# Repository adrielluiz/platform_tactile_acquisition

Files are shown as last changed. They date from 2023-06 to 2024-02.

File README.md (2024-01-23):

# Dynamic Tactile Data Acquisition Platform

### Overview

This repository hosts a Dynamic Tactile Data Acquisition Platform,  designed to facilitate tactile experiments across two axes (X and Z). It is a versatile tool aimed at researchers and engineers involved in tactile data collection and analysis.

### Features

- **Two-Axis Movement**: Precision-engineered to operate along both X and Z axes, ensuring comprehensive coverage for tactile experiments.
- **Dual Stepper Motors**: Employs two robust stepper motors, delivering smooth and accurate motion control.
- **Microcontroller**: Utilizes an STM32F401 MCU.
- **Integrated System Components**:
  - **Firmware**: C/C++ firmware for platform control.
  - **Software Interface**: A user-friendly Python-based software interface for movement planning and execution.
  - **Serial Communication**: Seamless serial communication protocol linking the software and firmware components.

### Repository Contents

- **Mechanical Structure 3D Files**: Detailed 3D models of the platform's mechanical structure for easy replication or modification.
- **Firmware Variants**: Two distinct firmware versions tailored to different stepper motor drivers.
- **Control Software**: Intuitive software designed for seamless interaction with the microcontroller unit.
- **PCB Design and Layout Files**: Comprehensive files for the printed circuit board (PCB) design.

### Getting Started

Please refer to the individual folders.

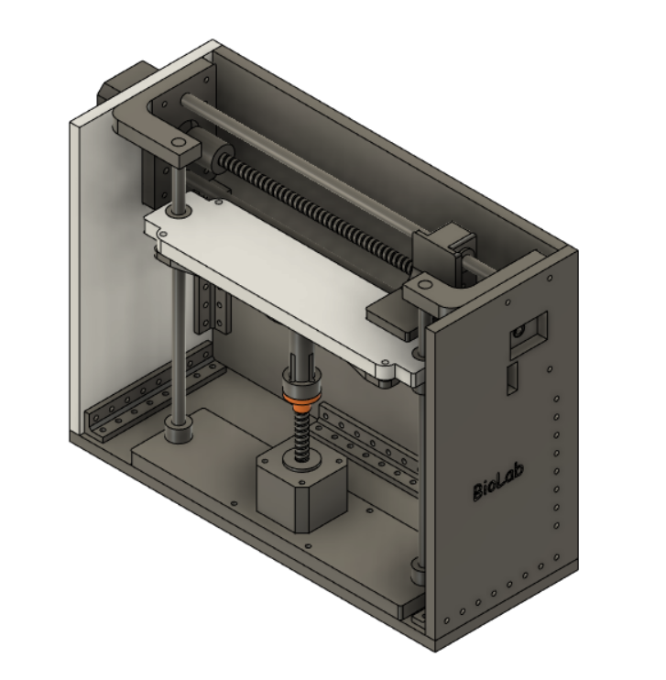
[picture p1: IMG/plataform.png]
plot


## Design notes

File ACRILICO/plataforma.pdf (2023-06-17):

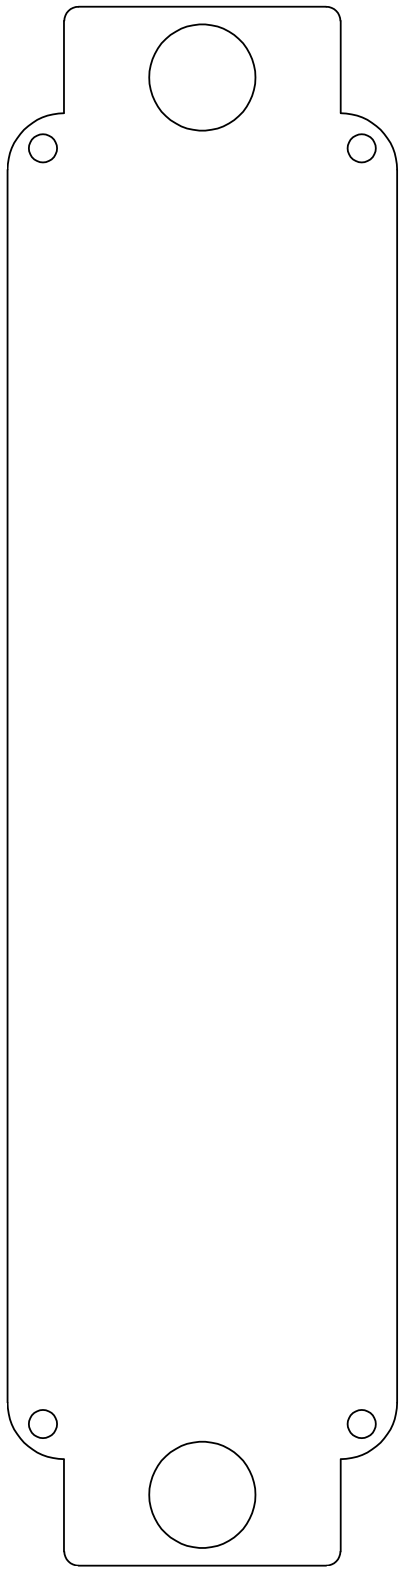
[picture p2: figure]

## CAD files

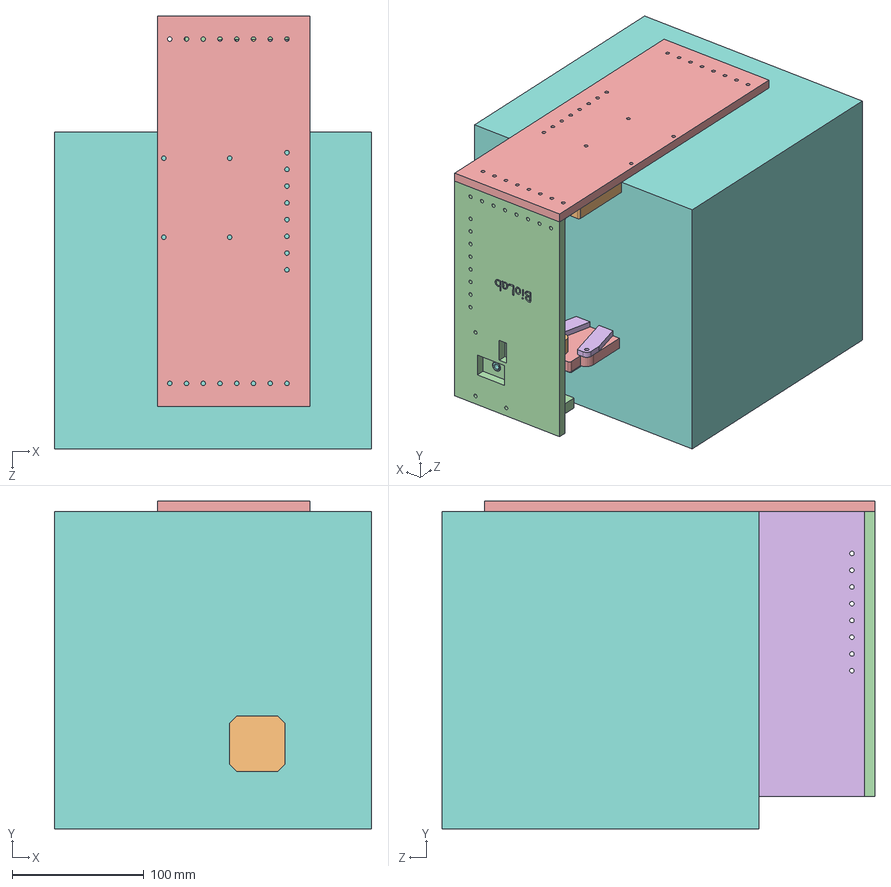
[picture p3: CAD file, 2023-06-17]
3D_files/MontagemPlataforma2.SLDASM
240.8 x 248.8 x 328.8 mm
SuporteMotor
motorPasso
acoplador
ContraApoioMotor
plataforma
suportePlataforma
guia200_5mm x 2
fusoTrapazoidal172_5mm
Rolamento
RolamentoLinear x 4
corredor
SensorFimdeCurso
motorPasso para fuso
fusoTrapazoidal100_8mm
Castanha x 2
guia175.43_8mm x 2
suporteFusoGuiaMotor
acrilico1
acrilico2
acrilico3
acrilico4
cantoneira x 5

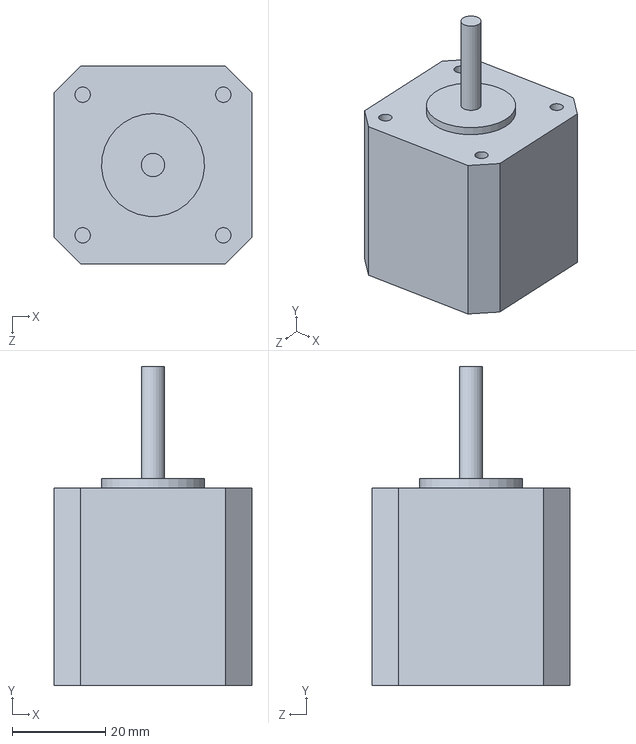
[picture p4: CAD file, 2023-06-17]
3D_files/motorPasso.SLDPRT
42.3 x 68.3 x 42.3 mm

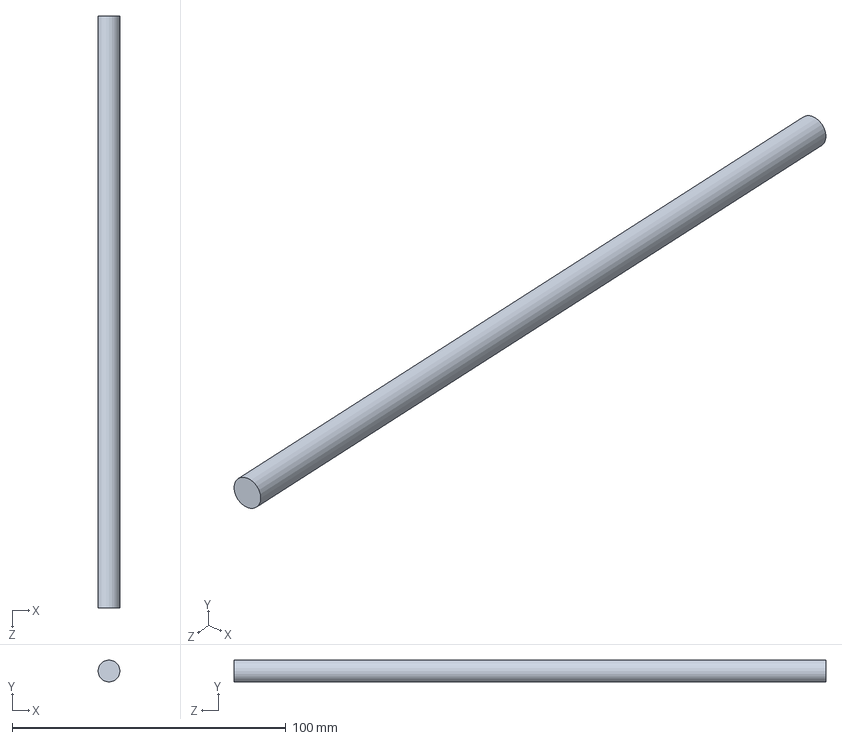
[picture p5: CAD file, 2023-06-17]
3D_files/guia175.43_8mm.SLDPRT
8.00 x 8.00 x 216.2 mm

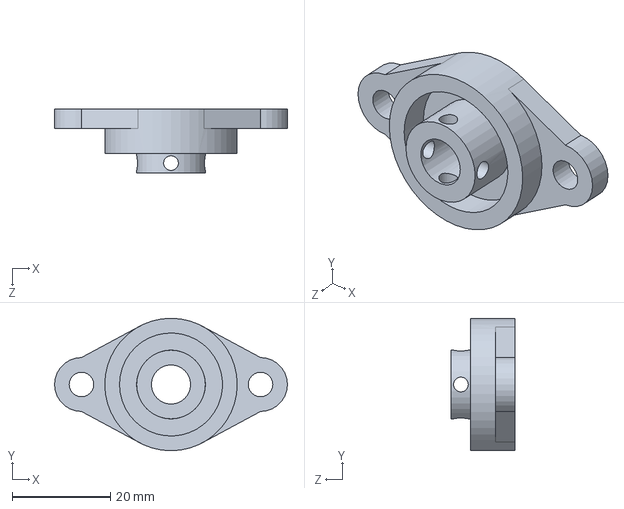
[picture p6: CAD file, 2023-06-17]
3D_files/Rolamento.SLDPRT
47.5 x 27.0 x 13.0 mm

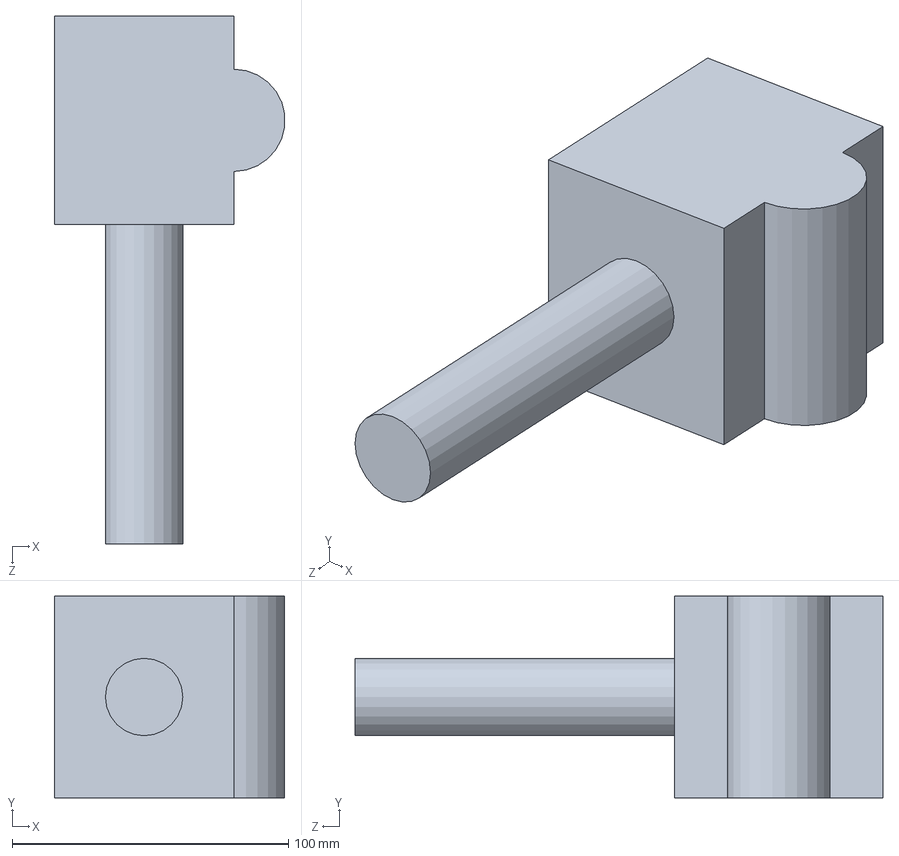
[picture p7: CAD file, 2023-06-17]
3D_files/macaco.SLDPRT
83.4 x 73.0 x 191.0 mm

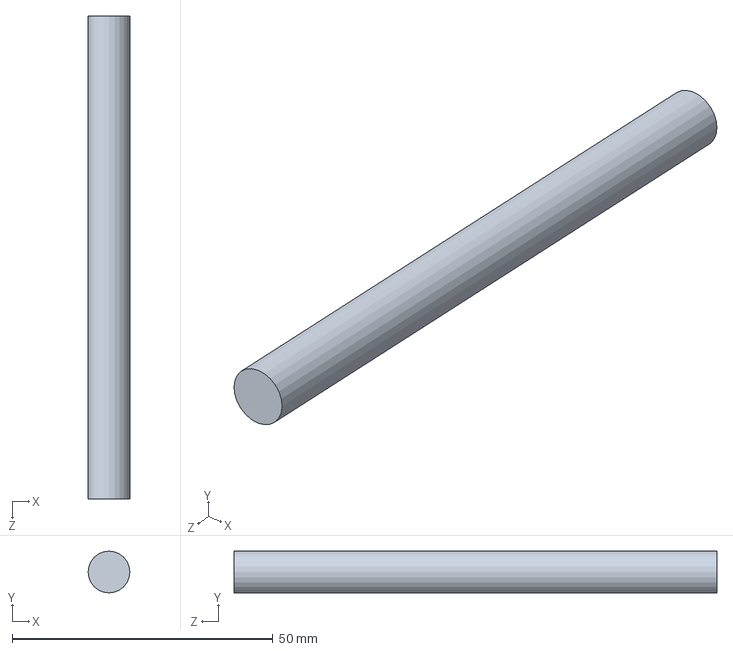
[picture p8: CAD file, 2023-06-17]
3D_files/guia146_8.SLDPRT
8.00 x 8.00 x 92.6 mm

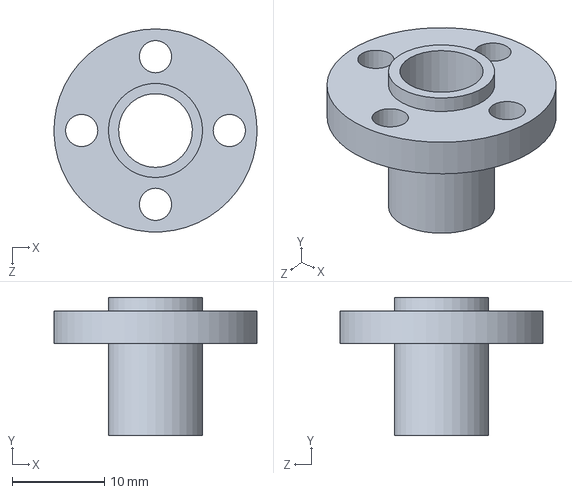
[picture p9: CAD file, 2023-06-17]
3D_files/Castanha.SLDPRT
22.0 x 15.0 x 22.0 mm

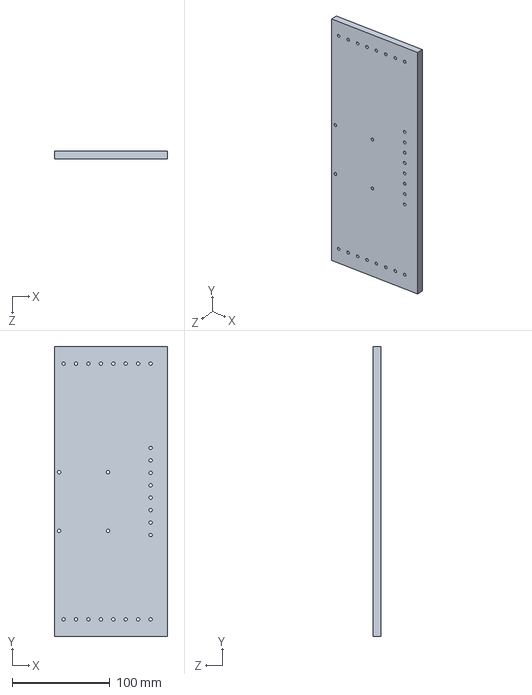
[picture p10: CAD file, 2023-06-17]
3D_files/acrilico3.SLDPRT
116.0 x 296.5 x 8.00 mm

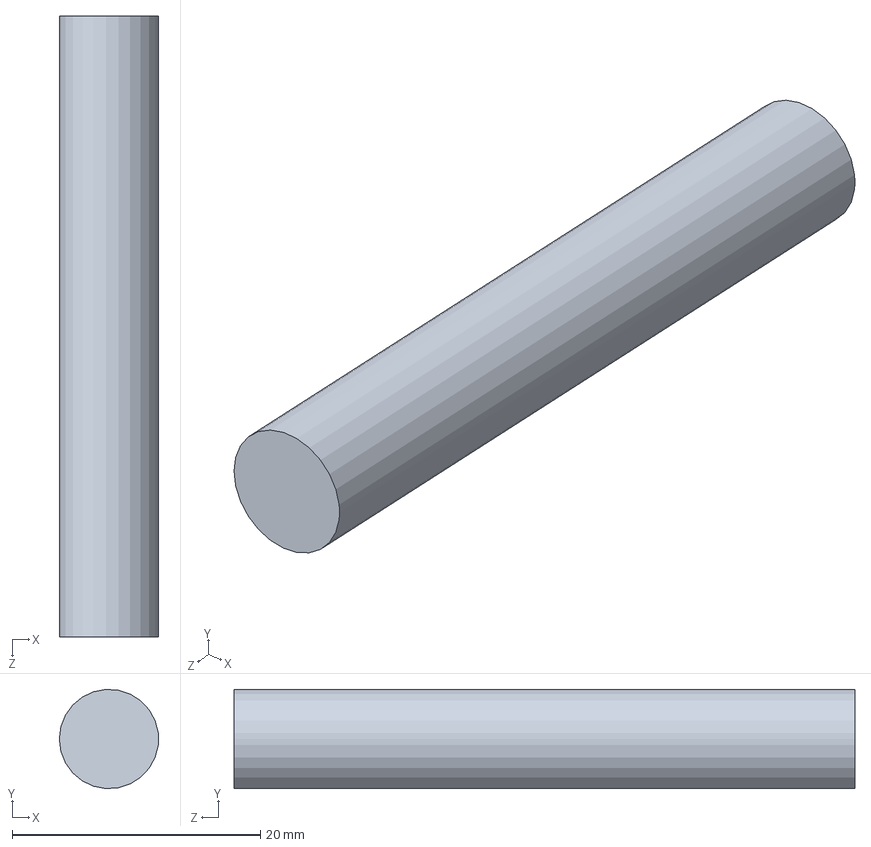
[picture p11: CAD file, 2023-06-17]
3D_files/guia100_8.SLDPRT
8.00 x 7.98 x 50.0 mm

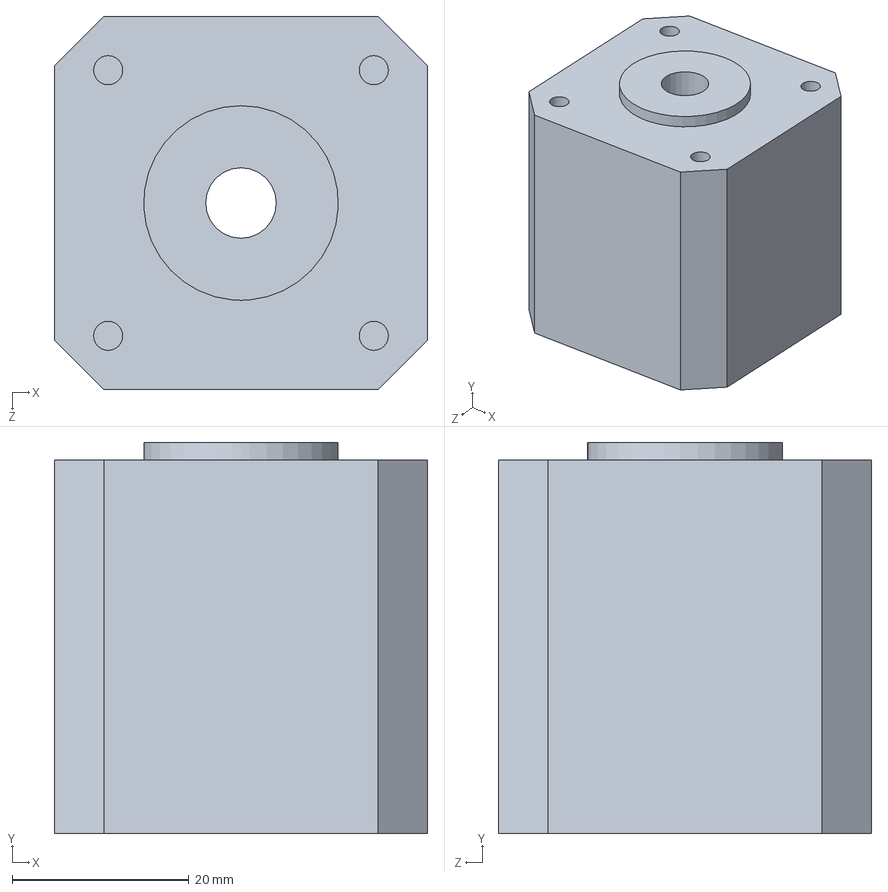
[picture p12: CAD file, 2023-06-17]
3D_files/motorPasso para fuso.SLDPRT
42.3 x 44.3 x 42.3 mm

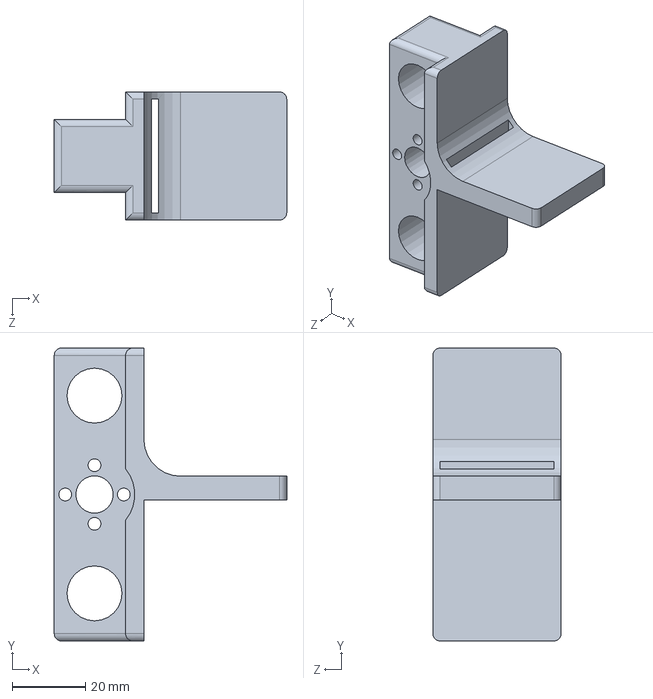
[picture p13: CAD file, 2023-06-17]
3D_files/corredor.SLDPRT
63.5 x 80.0 x 35.0 mm

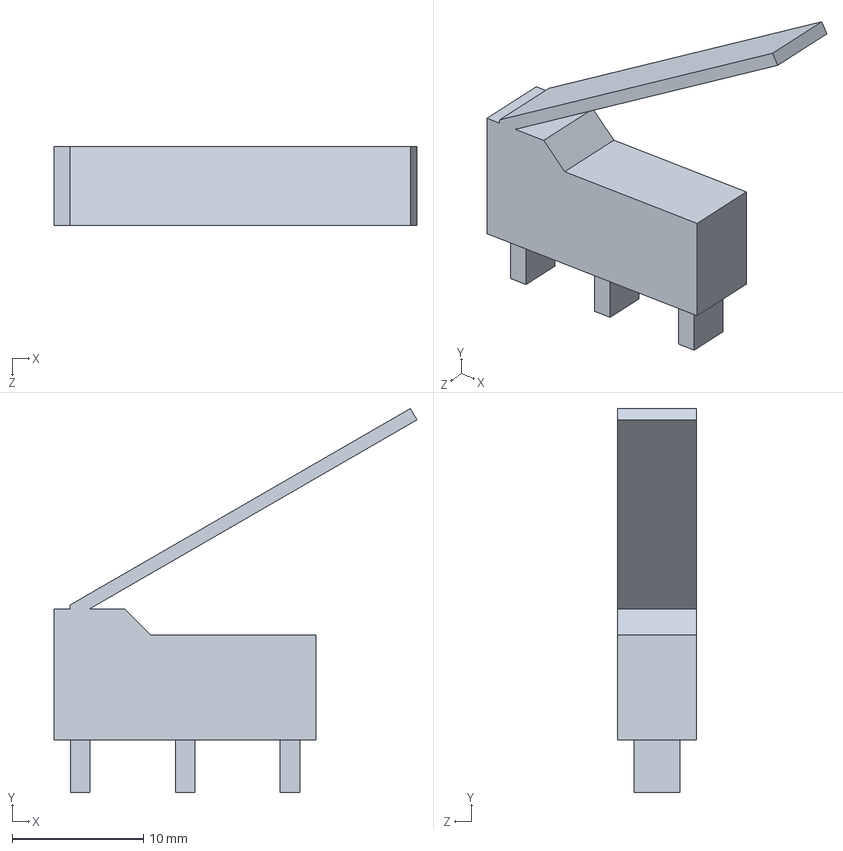
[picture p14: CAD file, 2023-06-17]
3D_files/SensorFimdeCurso.SLDPRT
27.7 x 29.3 x 6.00 mm

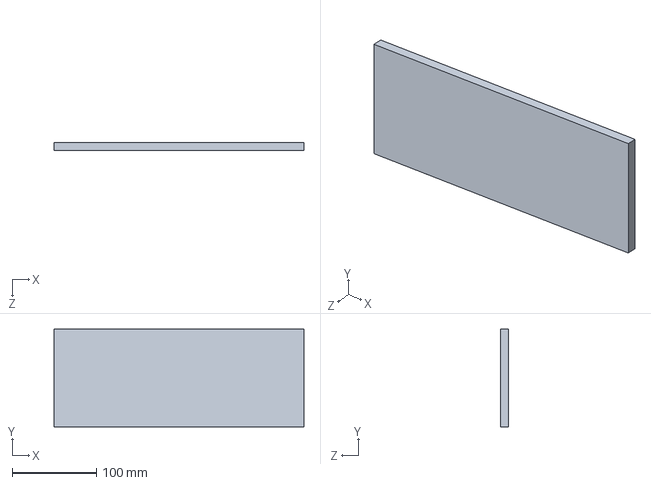
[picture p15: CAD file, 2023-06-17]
3D_files/acrilico5.SLDPRT
296.5 x 116.0 x 10.0 mm

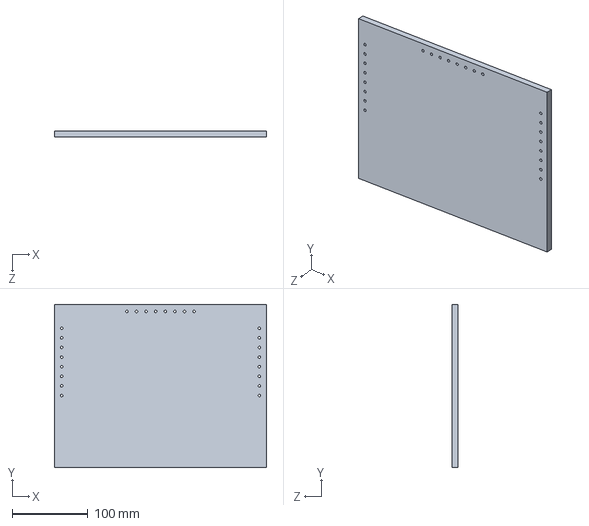
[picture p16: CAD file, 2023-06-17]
3D_files/acrilico4.SLDPRT
280.5 x 216.2 x 8.00 mm

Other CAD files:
3D_files/guia200_5mm.SLDPRT
3D_files/fusoTrapazoidal172_5mm.SLDPRT
3D_files/cantoneira.SLDPRT
3D_files/SuporteMotor.SLDPRT
3D_files/ContraApoioMotor.SLDPRT
3D_files/RolamentoLinear.SLDPRT
3D_files/acoplador.SLDPRT
3D_files/acoplador_guiamotor.SLDPRT
3D_files/acrilico1.SLDPRT
3D_files/acrilico2.SLDPRT
3D_files/box.SLDPRT
3D_files/fuso240mm.SLDPRT
3D_files/fusoTrapazoidal100_8mm.SLDPRT
3D_files/fusoTrapazoidal105_5mm.SLDPRT
3D_files/fusoTrapazoidal240mm - Copia.SLDPRT
3D_files/fusoTrapazoidal240mm.SLDPRT
3D_files/guia240mm.SLDPRT
3D_files/plataforma.SLDPRT
3D_files/suporteFusoGuiaMotor.SLDPRT
3D_files/suportePlataforma.SLDPRT

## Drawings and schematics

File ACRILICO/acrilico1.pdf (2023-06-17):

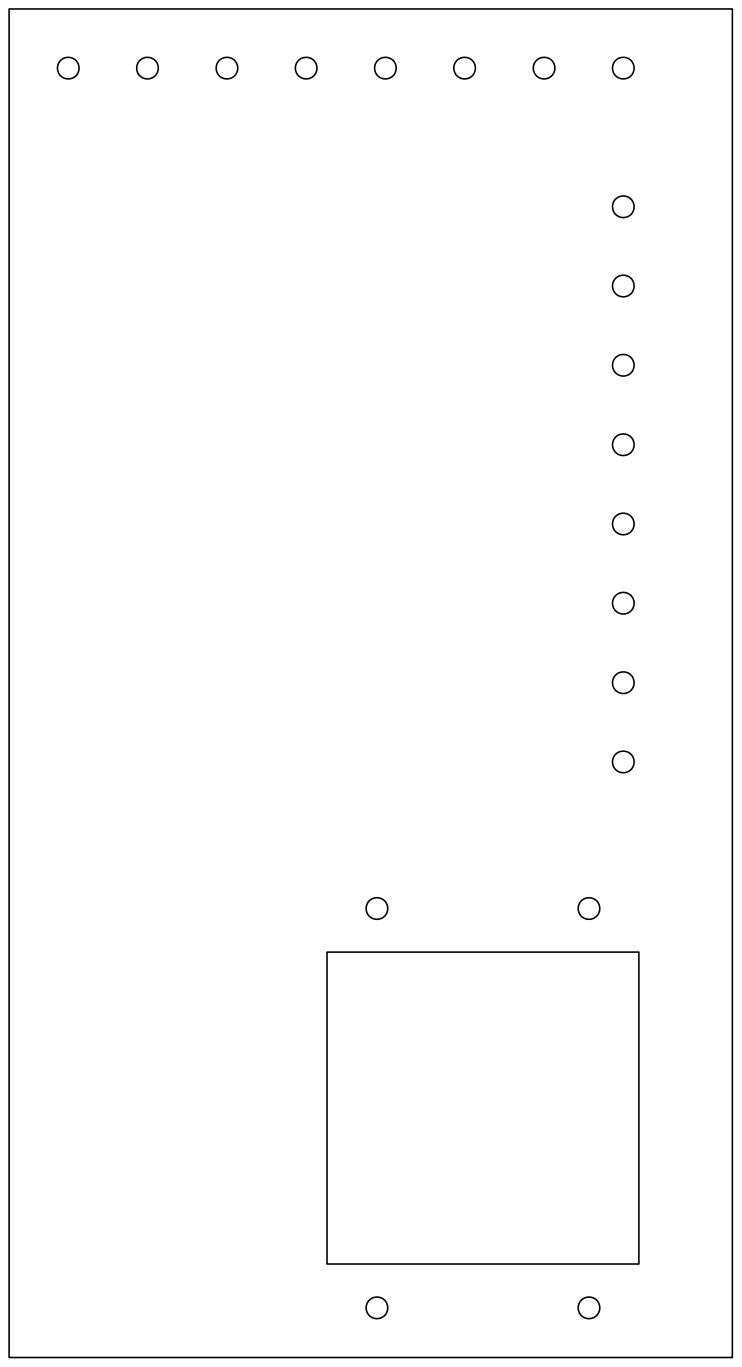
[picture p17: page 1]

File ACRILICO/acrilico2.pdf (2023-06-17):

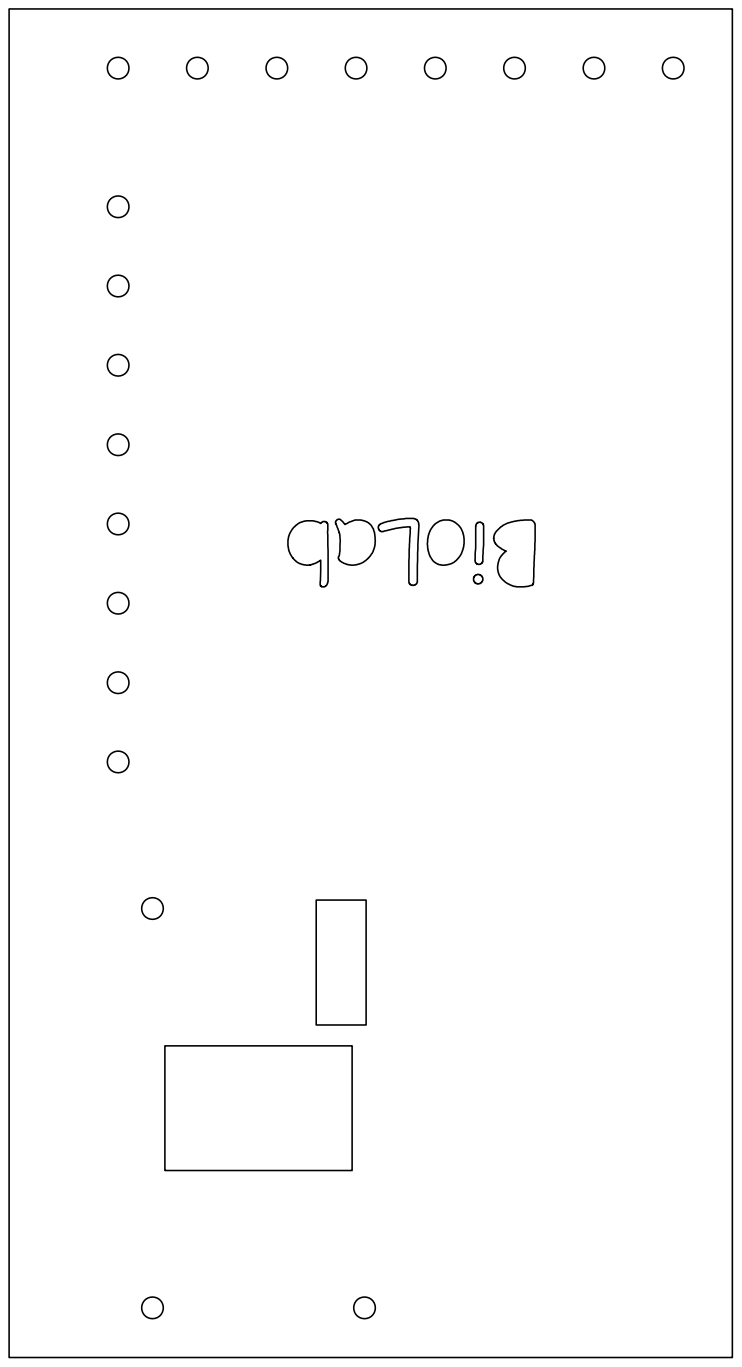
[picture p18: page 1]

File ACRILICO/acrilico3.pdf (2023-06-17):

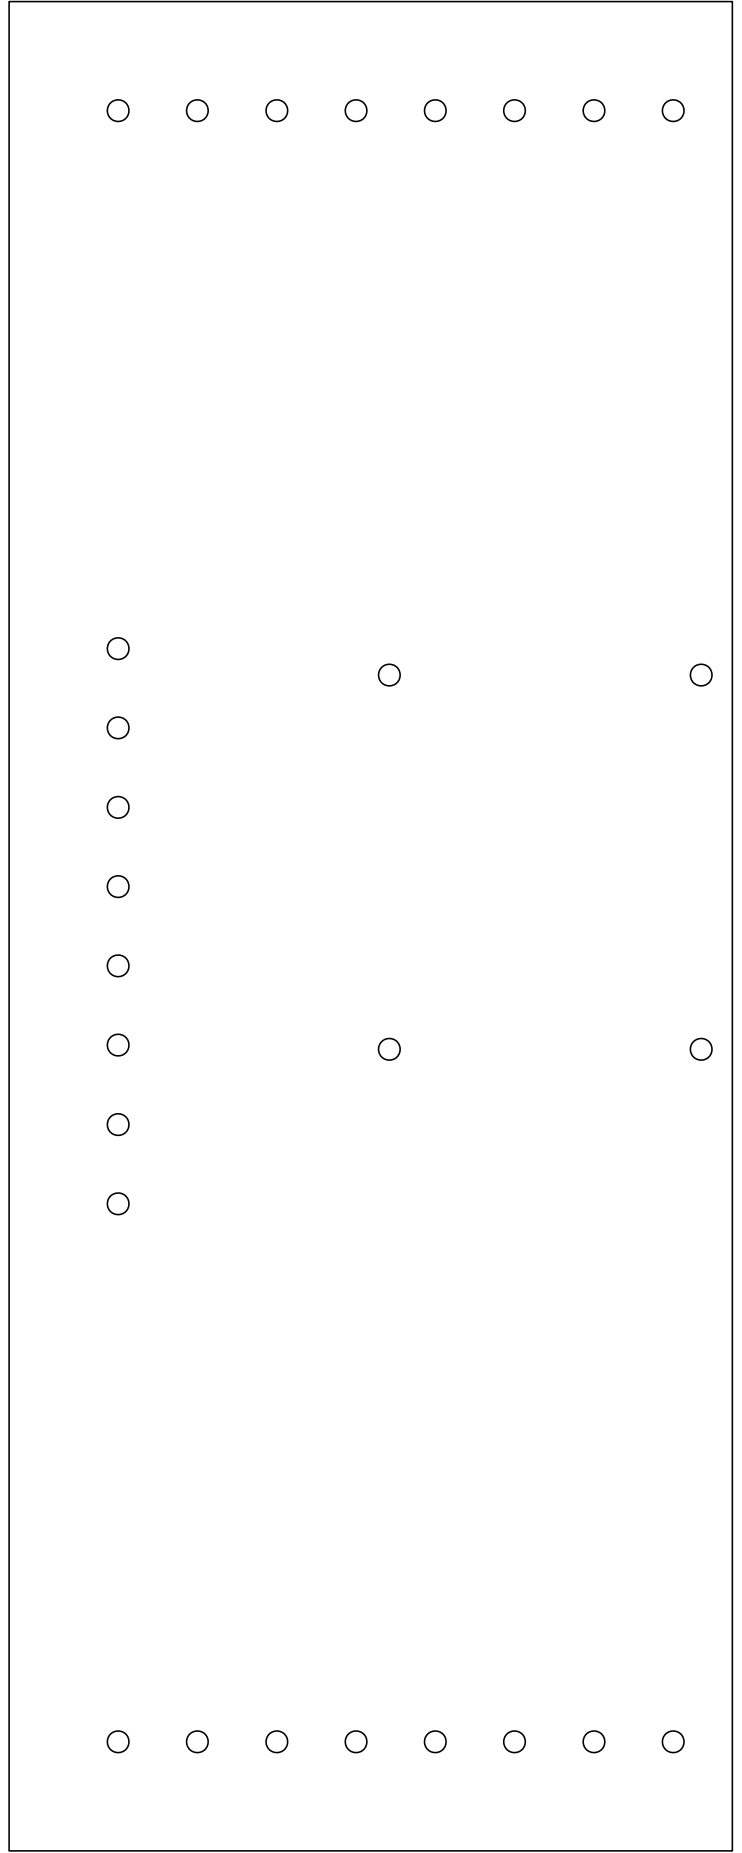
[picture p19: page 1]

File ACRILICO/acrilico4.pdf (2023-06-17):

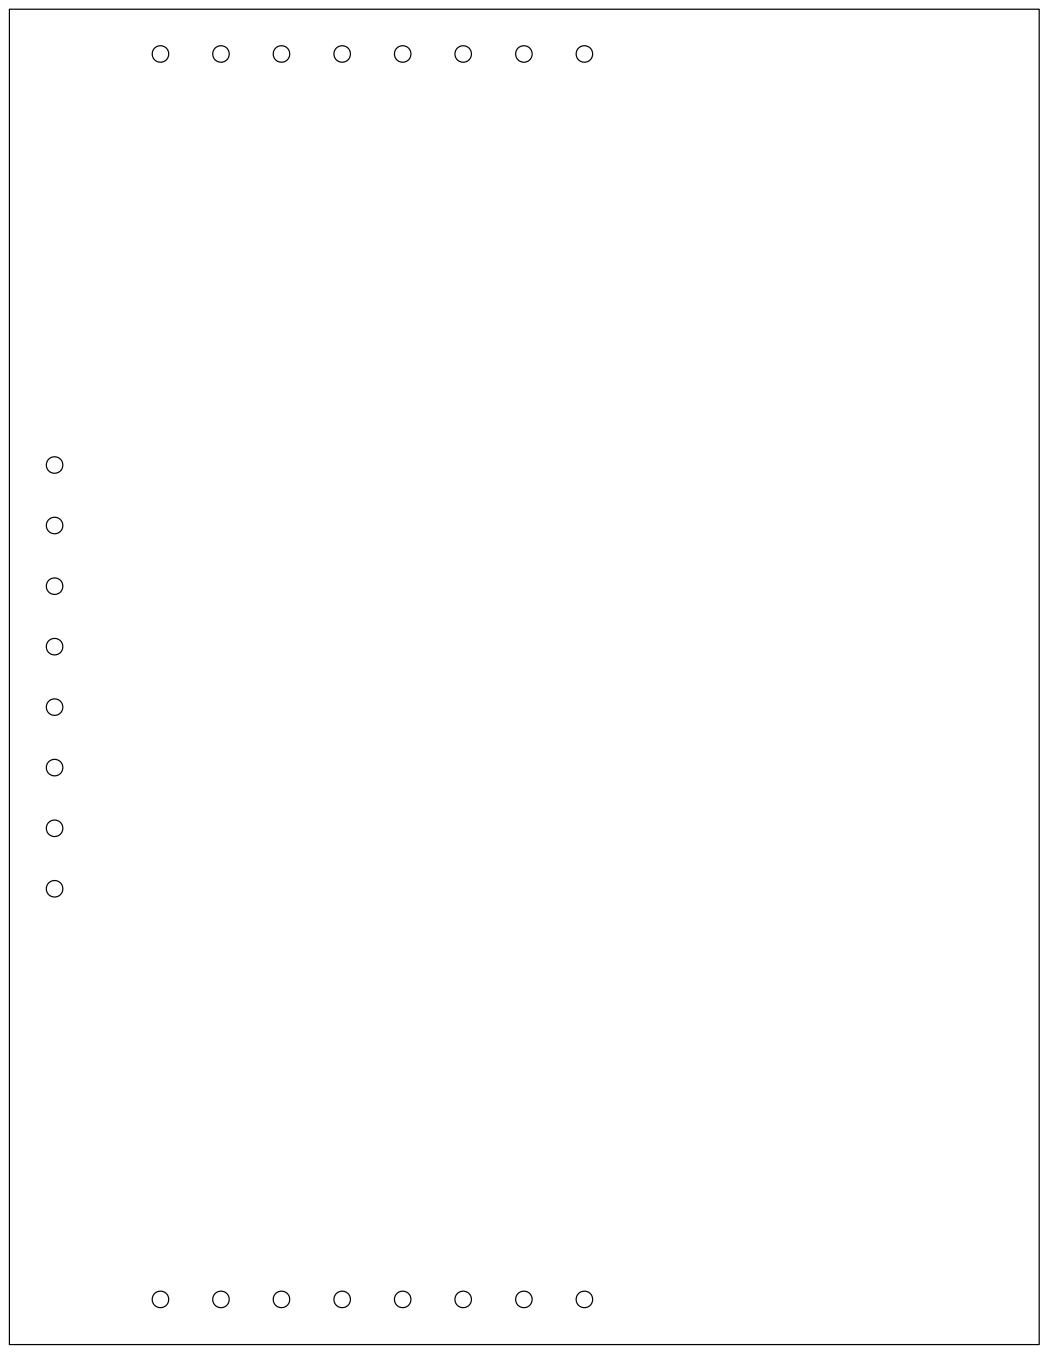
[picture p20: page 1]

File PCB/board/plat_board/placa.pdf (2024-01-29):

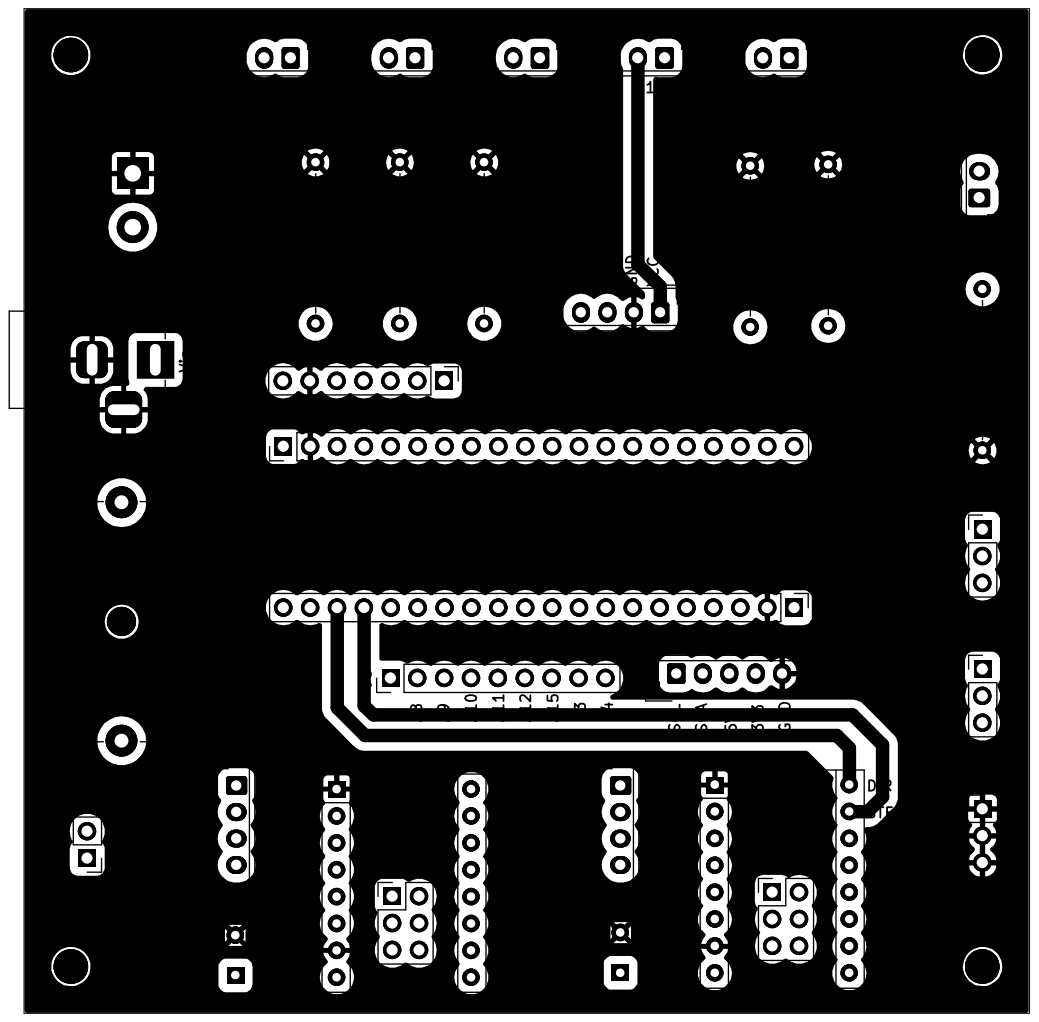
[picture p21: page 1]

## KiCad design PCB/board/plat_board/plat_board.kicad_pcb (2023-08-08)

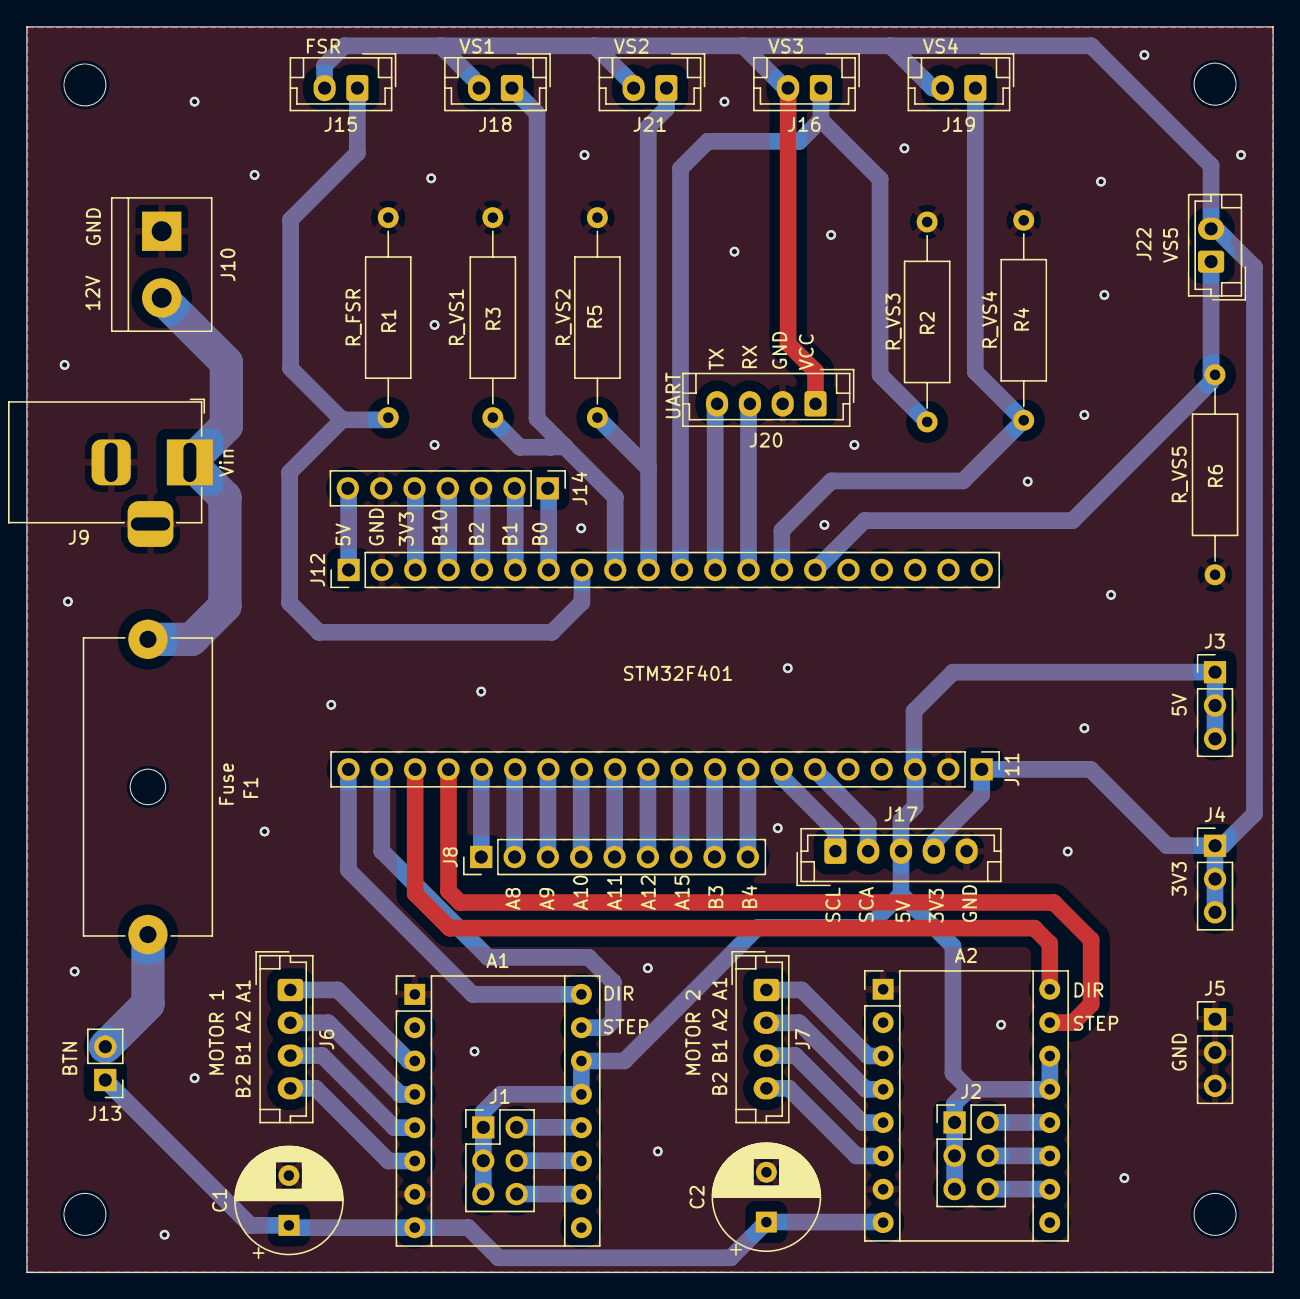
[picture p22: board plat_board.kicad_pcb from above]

Board: 2 copper layers, 95.0 x 94.9 mm, 37 parts (0 on the bottom side), 49 nets.

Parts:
A1, A2: Pololu_Breakout_DRV8825; Pololu_Breakout-16_15.2x20.3mm
C1, C2: 100uF; CP_Radial_D8.0mm_P3.80mm
F1: Fuse; Fuseholder_Cylinder-5x20mm_Schurter_0031_8201_Horizontal_Op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
H1, H2, H3, H4: MountingHole; MountingHole_3.2mm_M3
J1: Step_Select1; PinHeader_2x03_P2.54mm_Vertical
J2: Step_Select2; PinHeader_2x03_P2.54mm_Vertical
J3: Conn_Ex_5V; PinHeader_1x03_P2.54mm_Vertical
J4: Conn_Ex_3v3; PinHeader_1x03_P2.54mm_Vertical
J5: Conn_Ext_GND; PinHeader_1x03_P2.54mm_Vertical
J6: MOTOR1; JST_EH_B4B-EH-A_1x04_P2.50mm_Vertical
J7: MOTOR2; JST_EH_B4B-EH-A_1x04_P2.50mm_Vertical
J8: Conn_Extra; PinHeader_1x09_P2.54mm_Vertical
J9: Font; BarrelJack_Horizontal
J10: VIN; TerminalBlock_bornier-2_P5.08mm
J11, J12: STM32F4; PinHeader_1x20_P2.54mm_Vertical
J13: Btn_OnOff; PinHeader_1x02_P2.54mm_Vertical
J14: Conn_Ext2; PinHeader_1x07_P2.54mm_Vertical
J15: FSR; JST_EH_B2B-EH-A_1x02_P2.50mm_Vertical
J16: VS3; JST_EH_B2B-EH-A_1x02_P2.50mm_Vertical
J17: MPU; JST_EH_B5B-EH-A_1x05_P2.50mm_Vertical
J18: VS1; JST_EH_B2B-EH-A_1x02_P2.50mm_Vertical
J19: VS4; JST_EH_B2B-EH-A_1x02_P2.50mm_Vertical
J20: UART; JST_EH_B4B-EH-A_1x04_P2.50mm_Vertical
J21: VS2; JST_EH_B2B-EH-A_1x02_P2.50mm_Vertical
J22: VS5; JST_EH_B2B-EH-A_1x02_P2.50mm_Vertical
R1: R_FSR; R_Axial_DIN0309_L9.0mm_D3.2mm_P15.24mm_Horizontal
R2: R_VS3; R_Axial_DIN0309_L9.0mm_D3.2mm_P15.24mm_Horizontal
R3: R_VS1; R_Axial_DIN0309_L9.0mm_D3.2mm_P15.24mm_Horizontal
R4: R_VS4; R_Axial_DIN0309_L9.0mm_D3.2mm_P15.24mm_Horizontal
R5: R_VS2; R_Axial_DIN0309_L9.0mm_D3.2mm_P15.24mm_Horizontal
R6: R_VS5; R_Axial_DIN0309_L9.0mm_D3.2mm_P15.24mm_Horizontal

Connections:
/3v3: J4.1, J4.2, J4.3, J11.1, J15.2, J16.2, J17.4, J18.2, J19.2, J20.1, J21.2, J22.2
/5V: A1.13 (~RST), A1.14 (~SLP), A2.13 (~RST), A2.14 (~SLP), J1.1, J1.3, J1.5, J2.1, J2.3, J2.5, J3.1, J3.2, J3.3, J11.3, J17.3
/12V: A1.8 (VMOT), A2.8 (VMOT), C1.1, C2.1, J13.1
/FSR: J12.8, J15.1, R1.2
/M0_1: A1.10 (M0), J1.6
/M0_2: A2.10 (M0), J2.6
/M1_DIR: A1.16 (DIR), J11.20
/M1_STEP: A1.15 (STEP), J11.19
/M2_1: A1.12 (M2), J1.2
/M2_2: A2.12 (M2), J2.2
/M2_DIR: A2.16 (DIR), J11.18
/M2_STEP: A2.15 (STEP), J11.17
/MPU_SCA: J11.6, J17.2
/MPU_SCL: J11.7, J17.1
/UART_RX: J12.12, J20.4
/UART_TX: J12.13, J20.3
/VS1: J12.9, J18.1, R3.2
/VS2: J12.10, J21.1, R5.2
/VS3: J12.11, J16.1, R2.2
/VS4: J12.14, J19.1, R4.2
/VS5: J12.15, J22.1, R6.2
/Vin: F1.1, J9.1, J10.2
GND: A1.1 (GND), A1.7 (GND), A2.1 (GND), A2.7 (GND), C1.2, C2.2, J5.1, J5.2, J5.3, J9.2, J9.3, J10.1, J11.2, J12.2, J14.6, J17.5, J20.2, R1.1, R2.1, R3.1, R4.1, R5.1, R6.1
unnamed: A1.4 (A1), J6.2
unnamed: A1.3 (A2), J6.1
unnamed: A1.5 (B1), J6.3
unnamed: A1.6 (B2), J6.4
unnamed: A1.11 (M1), J1.4
unnamed: A2.4 (A1), J7.2
unnamed: A2.3 (A2), J7.1
unnamed: A2.5 (B1), J7.3
unnamed: A2.6 (B2), J7.4
unnamed: A2.11 (M1), J2.4
unnamed: J8.9, J11.8
unnamed: J8.8, J11.9
unnamed: J8.7, J11.10
unnamed: J8.6, J11.11
unnamed: J8.5, J11.12
unnamed: J8.4, J11.13
unnamed: J8.3, J11.14
unnamed: J8.2, J11.15
unnamed: J8.1, J11.16
unnamed: J12.1, J14.7
unnamed: J12.3, J14.5
unnamed: J12.4, J14.4
unnamed: J12.5, J14.3
unnamed: J12.6, J14.2
unnamed: J12.7, J14.1
unnamed: F1.2, J13.2

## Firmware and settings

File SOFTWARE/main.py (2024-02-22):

from PyQt5.QtWidgets import QApplication, QMainWindow, QApplication, QMessageBox, QListWidgetItem
from PyQt5.QtCore import Qt, QThread, pyqtSignal, QTimer
from PyQt5.QtGui import QColor
from main_window import Ui_MainWindow
import sys
from serial_port import SerialConn
from excel import Excel
from serial import *
import log
from threading import Event
from queue import Queue
from serial_cmd import SerialCmd
from threading import *
import time
from exp import RunExperiment

class MainWin(QMainWindow):
    work_requested = pyqtSignal()

    def __init__(self, *args, **kwargs):
        super().__init__(*args, **kwargs)

        self.main_win = QMainWindow()
        self.ui = Ui_MainWindow()
        self.ui.setupUi(self.main_win)        

        self.stop = Event()
        self.txq = Queue()
        self.rxq = Queue()
        self.serial_task = SerialConn()
        
        self.mb_stop = Event()
        self.mb_txq = Queue()
        self.mb_rxq = Queue()
        self.mb_serial_task = SerialConn()

        self.ui.pbConectarSerial.clicked.connect(self.conn_serial)
        self.ui.pbConnMeasBoard.clicked.connect(self.conn_serial_mb)
        self.ui.pbSendMode.clicked.connect(self.send_mode)
        self.ui.pbSendFreq.clicked.connect(self.send_freq)
        self.ui.pbSendSpeed.clicked.connect(self.send_speed)
        self.ui.pbSendReadVar.clicked.connect(self.send_flags)
        self.ui.pbHomeX.clicked.connect(self.send_pos_home_x)
        self.ui.pbHomeZ.clicked.connect(self.send_pos_home_z)
        self.ui.pbSaveExcel.clicked.connect(self.save_excel)
        self.ui.pbStartRun1.clicked.connect(self.run_exp)
        self.ui.pbUpdateFileName.clicked.connect(self.update_file_name)
        self.ui.pbStopRun1.clicked.connect(self.run1_stop)
        self.ui.pbUpdateCOMList.clicked.connect(self.update_com_ports)

        self.ui.horizontalSliderX.sliderReleased.connect(self.send_pos_x)
        self.ui.verticalSliderZ.sliderReleased.connect(self.send_pos_z)    

        self.excel = Excel()           

        self.worker_thread = QThread()
        self.exp = RunExperiment(self.txq, 1)
        
        self.exp.progress_bar.connect(self.run1_update_progress)
        self.exp.msg_box.connect(self.run1_append_msg)
        self.work_requested.connect(self.exp.run)

        self.exp.moveToThread(self.worker_thread) 
        self.timer_init()
       
    def show(self):
        self.main_win.show()

    def update_com_ports(self):
        self.ui.comboBoxSerialPort.clear()
        self.ui.comboBoxMeasBoard.clear()
        ports = self.serial_task.get_ports_available()
        for port in ports:            
            self.ui.comboBoxSerialPort.addItem(port.device)
            self.ui.comboBoxMeasBoard.addItem(port.device)

    def conn_serial(self):
        print(self.ui.comboBoxSerialPort.currentText())

        if not self.serial_task.is_connected:        
            try:
                self.serial = Serial(port=self.ui.comboBoxSerialPort.currentText(),timeout=1,baudrate=115200)
            except Exception as e:
                log.logging.error(str(e))
                sys.exit(1)         
            else:
                self.serial_task.set_init_parameters(self.serial,self.rxq, self.txq, self.stop)
                self.serial_task.start()              
             
                self.ui.pbConectarSerial.setStyleSheet("background-color: lime")
                self.recv = Thread(target=self.recv_data)
                self.recv.start()

                self.txq.put(SerialCmd().set_restart())
                time.sleep(1)
        else:
            log.logging.error("Serial already opened")
            
    def conn_serial_mb(self):
        print(self.ui.comboBoxMeasBoard.currentText())

        if not self.mb_serial_task.is_connected:        
            try:
                self.mb_serial = Serial(port=self.ui.comboBoxMeasBoard.currentText(),timeout=1,baudrate=230400)
            except Exception as e:
                log.logging.error(str(e))
                sys.exit(1)         
            else:
                self.mb_serial_task.set_init_parameters(self.mb_serial,self.mb_rxq, self.mb_txq, self.mb_stop)
                self.mb_serial_task.start()              
             
                self.ui.pbConnMeasBoard.setStyleSheet("background-color: lime")
                self.mb_recv = Thread(target=self.mb_recv_data)
                self.mb_recv.start()
                time.sleep(1)
        else:
            log.logging.error("Serial already opened")        

    def recv_data(self):
        while not self.stop.is_set():
            new_cmd = False
            try:
                cmd = self.rxq.get(True, 1)
            except Exception as e:
                time.sleep(0.5)
            else:
                new_cmd = True

            if new_cmd:
                self.check_cmd(cmd)
                
    def mb_recv_data(self):
        while not self.mb_stop.is_set():
            new_cmd = False
            try:
                cmd = self.mb_rxq.get(True, 1)
            except Exception as e:
                time.sleep(0.5)
            else:
                new_cmd = True

            if new_cmd:
                try:    
                    log.logging.info('Meas -> TS: {}\t LC: {}\t RS:{}\n'.format(cmd['ts'], cmd['load_cell'], cmd['resistive_sensor']))
                    self.excel.append_meas_board(cmd['ts'], cmd['load_cell'], cmd['resistive_sensor'])
                    self.show_rx_label_meas_board()
                except Exception:
                    print(cmd) 

    def check_cmd(self,cmd):
        if 'command' not in cmd:
            return 
        
        tab = self.ui.tabWidget.tabText(self.ui.tabWidget.currentIndex())

        if cmd['command'] == 'position':
            x = cmd['params']['x']
            z = cmd['params']['z']
            ts = cmd['params']['ts']
            log.logging.debug('New position x: {} z: {} ts: {}'.format(x, z, ts))

            if tab == "Test":
                self.ui.lcdPositionX.display(x)
                self.ui.lcdPositionZ.display(z)
            elif tab == "Run 1":    
                self.exp.set_pos_z_read(z)    

            #self.excel.append_pos(x, z, ts)
            self.show_rx_label_plat()
            
        elif cmd['command'] == 'fsr':
            fsr = cmd['params']['value']
            log.logging.debug('New fsr: {}'.format(fsr))
            if tab == "Test":
                self.ui.lcdFSR.display(fsr)
            elif tab == "Run 1":    
                self.exp.set_fsr_read(fsr)
           
            self.excel.append_fsr(fsr)

        elif cmd['command'] == 'ok':
            if tab == "Run 1":
                self.exp.read_ok = True    

    def send_mode(self):
        if self.serial_task.is_connected:
            if self.ui.rbModeIdle.isChecked():
                self.txq.put(SerialCmd().set_mode("idle"))
            elif self.ui.rbModeReadData.isChecked():
                self.txq.put(SerialCmd().set_mode("read"))  

    def send_speed(self):
        if self.serial_task.is_connected: 
            speed  = self.ui.spinBoxSpeed.value()
            if self.ui.rbSpeedX.isChecked():
                self.txq.put(SerialCmd().set_speed("x", speed))     
            elif self.ui.rbSpeedZ.isChecked():
                self.txq.put(SerialCmd().set_speed("z", speed))

    def send_freq(self):
        if self.serial_task.is_connected: 
            freq = self.ui.spinBoxFreq.value()
            self.txq.put(SerialCmd().set_freq(freq))
            pass

    def read_checkbox_int(self, value):
        if value == True:
            return 1
        else:
            return 0    

    def send_flags(self):
        if self.serial_task.is_connected: 
            pos = self.read_checkbox_int(self.ui.checkBoxPosition.isChecked())
            mpu = self.read_checkbox_int(self.ui.checkBoxMPU.isChecked())
            fsr = self.read_checkbox_int(self.ui.checkBoxFSR.isChecked())
            vs  = self.read_checkbox_int(self.ui.checkBoxVS.isChecked())
            self.txq.put(SerialCmd().set_flags_read(pos, mpu, fsr, vs))        

    def send_pos_home_x(self):   
        if self.serial_task.is_connected: 
            self.txq.put(SerialCmd().set_pos("x", "home"))     
            self.ui.horizontalSliderX.setValue(0)   
            #self.ui.pbHomeX.setEnabled(False)  

    def send_pos_home_z(self):   
        if self.serial_task.is_connected: 
            self.txq.put(SerialCmd().set_pos("z", "home"))  
            self.ui.verticalSliderZ.setValue(0)
            #self.ui.pbHomeZ.setEnabled(False)  

    def send_pos_x(self):
        if self.serial_task.is_connected: 
            pos_x = self.ui.horizontalSliderX.value() * 1000
            self.txq.put(SerialCmd().set_pos("x", pos_x))      

    def send_pos_z(self):
        if self.serial_task.is_connected: 
            pos_z = self.ui.verticalSliderZ.value() * 1000
            self.txq.put(SerialCmd().set_pos("z", pos_z))         

    def save_excel(self):
        self.excel.save_file()        
        self.show_info_messagebox(f"Excel file {self.excel.filename} saved!")         
        sys.exit(1)   

    def show_info_messagebox(self, msg_write):
        msg = QMessageBox()
        msg.setIcon(QMessageBox.Information)
        msg.setText(msg_write)        
        msg.setWindowTitle("Information")
        msg.exec_()        
  
    def update_file_name(self):
        self.excel.set_file_name(self.ui.lineEditFileName.text())

    def run_exp(self):
        if self.serial_task.is_connected:
            init_x  = self.ui.sbXinit.value()
            init_z  = self.ui.sbZinit.value()
            final_z  = self.ui.sbZmax.value()
            num  = self.ui.sbNumTests.value()
            
            if(final_z > init_z):
                self.excel.clean_data()
                self.exp.set_all_param(init_x, init_z, final_z, num)    
                self.worker_thread.start()
                self.work_requested.emit()
            else:
                self.show_info_messagebox("Final Z must be greater than Initial Z")

    def run1_update_progress(self, val):
        self.ui.progressBarRun1.setValue(val)

    def run1_append_msg(self, msg, type):
        item = QListWidgetItem(msg)
        
        if type == 'info':
            item.setForeground(QColor(Qt.darkGreen))
        elif type == 'error':
            item.setForeground(QColor(Qt.red))

        if 'Running New Test' in msg:
            item.setTextAlignment(Qt.AlignCenter)    
        
        self.ui.listWidgetRun1.addItem(item)

    def run1_stop(self):
        self.worker_thread.terminate()
        self.run1_append_msg("Run 1 stopped", "error")
            
    def timer_init(self):
        self.timer = QTimer()
        self.timer.timeout.connect(self.timer_cbk)
        self.timer.start(1000)    
        
    def timer_cbk(self):
        self.hide_rx_labels()  
        
    def hide_rx_labels(self):
        self.ui.lb_Rx_MeasBoard.setText("RX")
        self.ui.lbRxPlat.setText("RX")
        
    def show_rx_label_meas_board(self):
        self.ui.lb_Rx_MeasBoard.setText("<html><head/><body><p><span style=\" color:#00aa00;\">RX</span></p></body></html>")    
                
    def show_rx_label_plat(self):
        self.ui.lbRxPlat.setText("<html><head/><body><p><span style=\" color:#00aa00;\">RX</span></p></body></html>")  

    
if __name__ == "__main__": 
    app = QApplication(sys.argv)
    main_win = MainWin()
    main_win.update_com_ports()
    main_win.show()
    sys.exit(app.exec_())

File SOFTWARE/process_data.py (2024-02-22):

# Read an excel column and process the data using a butterworth filter
# Plot the data and the filtered data

import pandas as pd
import numpy as np
import matplotlib.pyplot as plt
from scipy.signal import butter, lfilter, freqz

# Read the excel file
def read_excel(file):
    df = pd.read_excel(file)
    return df

# Process the data using a butterworth filter
def butter_lowpass(cutoff, fs, order=5):
    nyq = 0.5 * fs
    normal_cutoff = cutoff / nyq
    b, a = butter(order, normal_cutoff, btype='low', analog=False)
    return b, a

def butter_lowpass_filter(data, cutoff, fs, order=5):
    b, a = butter_lowpass(cutoff, fs, order=order)
    y = lfilter(b, a, data)
    return y

# Plot the data and the filtered data
def plot_data(data, filtered_data, fs, cutoff):
    plt.figure()
    plt.plot(data, 'b-', label='data')
    plt.plot(filtered_data, 'g-', linewidth=2, label='filtered data')
    plt.xlabel('Sample')
    plt.ylabel('Amplitude')
    plt.title('Data and Filtered Data')
    plt.grid(True)
    plt.axis('tight')
    plt.legend(loc='upper left')
    plt.show()

# Main function
def main():
    file = 'plataform_data[6].xlsx'
    df = read_excel(file)
    data = df['ResistiveSensor'].values
    fs = 1000.0
    cutoff = 100.0
    order = 6
    filtered_data = butter_lowpass_filter(data, cutoff, fs, order)
    
    plot_data(filtered_data, filtered_data, fs, cutoff)

if __name__ == "__main__":
    main()
    

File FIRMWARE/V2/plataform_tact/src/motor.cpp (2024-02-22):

#include <Arduino.h>
#include <BasicStepperDriver.h>
#include "motor.h"
#include "hw.h"

#define MOTOR_FULL_STEP 1
#define MAX_STEPS_RELEASE_END_STOP 10
#define MOTOR_HOME_SPEED 30
#define MOTOR_STEPS_REV 200
#define MOTOR_INITIAL_SPEED_RPM 300
#define MOTOR1_uM_REV 12000
#define MOTOR2_UM_REV 8000

#define MOTOR_STEPS_REV 200.0
#define MOTOR1_MOVE_Um_REV 12000.0
#define MOTOR2_MOVE_Um_REV 8000.0

#define MOTOR1_STEP_TO_uM 200.0 / 12000.0
#define MOTOR2_STEP_TO_uM 200.0 / 8000.0

BasicStepperDriver motor[2] = {BasicStepperDriver(MOTOR_STEPS_REV, MOTOR1_DIR_PIN, MOTOR1_STP_PIN), BasicStepperDriver(MOTOR_STEPS_REV,  MOTOR2_DIR_PIN, MOTOR2_STP_PIN)};

volatile int motor_pos_step[2] = {0,0};
volatile int motor_pos_um[2] = {0,0};
long int motor_max_dist_um[2] = {PLATAFORM_MAX_DIST_X_uM, PLATAFORM_MAX_DIST_Z_uM};
int motor_steps_realease_end_stop[2] = {-MAX_STEPS_RELEASE_END_STOP, MAX_STEPS_RELEASE_END_STOP};

void motor_init(void)
{ 
    motor[0].begin(MOTOR_INITIAL_SPEED_RPM, MOTOR_FULL_STEP);
    motor[1].begin(MOTOR_INITIAL_SPEED_RPM, MOTOR_FULL_STEP);
}

bool motor_move(int motor_id, int step)
{
    volatile int pos_init = motor_pos_um[motor_id -1];

    step = step * (-1);
    
    motor[motor_id-1].startMove(step);

    while (motor[motor_id-1].nextAction() != 0) 
    {
        if(hw_sw_is_on(motor_id-1))
        {
            motor[motor_id-1].stop();
            return false;
        }

        motor_pos_um[motor_id -1] = pos_init-motor_convert_steps_to_um(motor_id, (motor[motor_id-1].getStepsCompleted() * motor[motor_id-1].getDirection()));

        // get actual position

    }

    return true;
}

void motor_set_speed(int motor_id, int speed_rpm)
{
    motor[motor_id-1].setRPM(speed_rpm);         
}

uint16_t motor_get_speed(int motor_id)
{
    return (uint16_t) motor[motor_id-1].getRPM();    
}

int motor_convert_um_steps(int motor_id, int pos_um)
{
    double um_to_step;
    
    if(motor_id == 1)
        um_to_step = (MOTOR_STEPS_REV / MOTOR1_MOVE_Um_REV) * pos_um;
    else if(motor_id == 2)
        um_to_step = (MOTOR_STEPS_REV / MOTOR2_MOVE_Um_REV)  * pos_um;  
    return (int) um_to_step;
}

int motor_convert_steps_to_um(int motor_id, int pos_steps)
{
    double pos_um;
    
    if(motor_id == 1)
        pos_um = (MOTOR1_MOVE_Um_REV / MOTOR_STEPS_REV) *pos_steps;
    else if(motor_id == 2)
        pos_um = (MOTOR2_MOVE_Um_REV / MOTOR_STEPS_REV) *pos_steps;  
    return (int) pos_um;
}

void motor_set_pos(int motor_id, int pos_um)
{
    int new_pos_um = pos_um;
   
    if(new_pos_um > motor_max_dist_um[motor_id-1])
        new_pos_um = motor_max_dist_um[motor_id-1];

    new_pos_um = new_pos_um - motor_pos_um[motor_id -1];
        
    int pos_steps = motor_convert_um_steps(motor_id, new_pos_um);

    if(motor_move(motor_id, pos_steps))
        motor_pos_um[motor_id -1] = pos_um;
    else
        motor_pos_um[motor_id -1] = 0;
}

int motor_get_pos(int motor_id)
{
    return motor_pos_um[motor_id-1];    
}

void motor_set_pos_home(int motor_id)
{
    int pos_steps = motor_convert_um_steps(motor_id, motor_max_dist_um[motor_id-1]);

    // find end stop

    motor[motor_id-1].startMove(pos_steps);

    while (motor[motor_id-1].nextAction() != 0) 
    {
        if(hw_sw_is_on(motor_id-1))
        {
            motor[motor_id-1].stop();
            break;
        }
    }

    hw_timer_delay_ms(100);

    // release end stop

    motor[motor_id-1].startMove(-400);

    while (motor[motor_id-1].nextAction() != 0) 
    {
        if(!hw_sw_is_on(motor_id-1))
        {
            hw_timer_delay_ms(10);
            motor[motor_id-1].stop();
            break;
        }
    }
    
    motor_pos_um[motor_id -1] = 0;
}

void motor_test_loop(void)
{
    motor_move(1, 1000);
    motor_move(1, -1000);

    hw_timer_delay_ms(5000);
}

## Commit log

2023-05-11 Adição de comandos
2023-06-17 Adding new files
    [Castanha.SLDPRT, ContraApoioMotor.SLDPRT, MontagemPlataforma2.SLDASM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]
2023-06-19 Correção de bugs no fw
    [app.cpp, cmd.cpp, hw.cpp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]
2023-06-22 Adição de componentes na gui
2023-06-26 Adição de dados para excel
2023-06-26 Adicionando interface de test
2023-06-27 Adicionando função de executar tafera repetidamente
2023-07-27 Adicionando arquivos da nova PCB
    [plat_board.kicad_pcb]
2023-08-08 Adding image
    [plat_board.kicad_pcb]
2024-01-29 Removing unecessary files
    [plat_board.kicad_sch, platt.kicad_pcb, platt.kicad_sch]
